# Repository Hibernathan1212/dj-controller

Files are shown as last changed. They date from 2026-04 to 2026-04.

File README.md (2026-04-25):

# DJ Controller

A MIDI jogless DJ controller similar to the Native Instruments S8 and D2 and X1 and Z1. Planning for it to just be a midi controller with knobs for mixing and controlling loops as well as buttons for play/pausing and others usually found on dj decks. Follows a modular design with the deck modules (2 on other side) and the mixer module which will have controls for 4 audio channels.

## Features

- Fully modular system
- 4 Audio track/channel support

## CAD

Consists of a base and a top lid that slots in a lip on the base. PCB is mounted to the lid with m2 screws that go into the faders and with the mx switches.

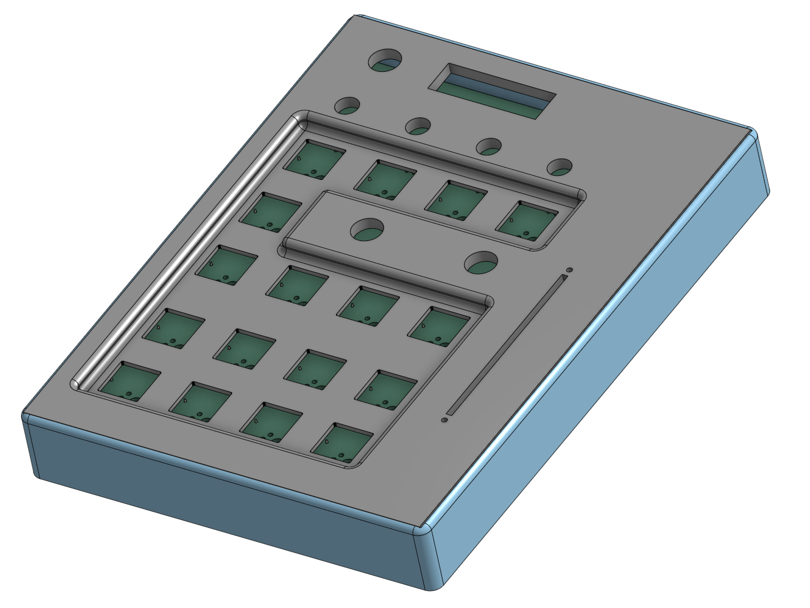
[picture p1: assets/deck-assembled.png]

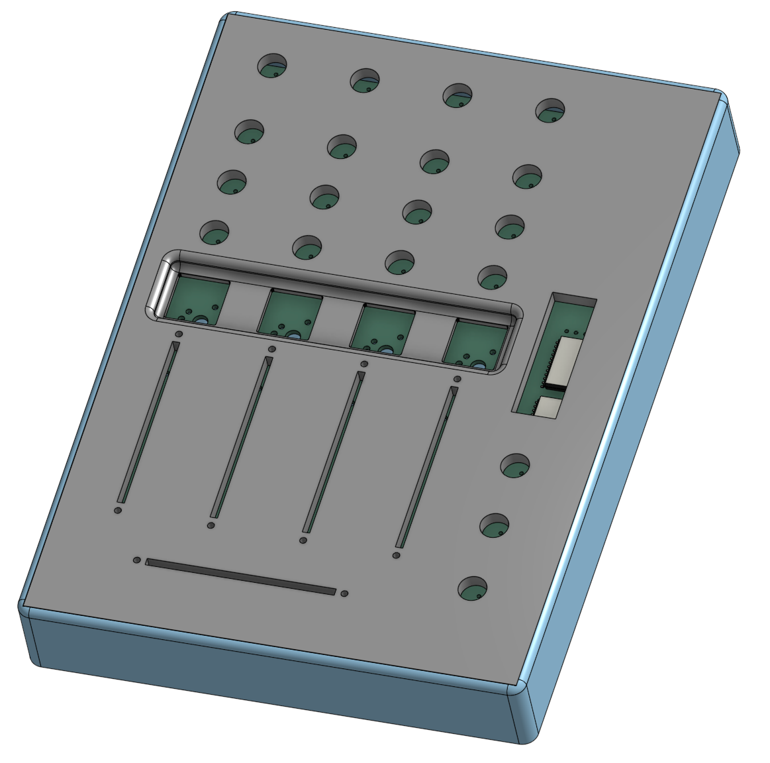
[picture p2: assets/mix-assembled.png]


Onshape links:
[mixer](https://cad.onshape.com/documents/8781b8df6f967f1c6b6a95c1/w/5dca202985c09c767b10b646/e/c48e65838657ec88be66024d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)
[deck](https://cad.onshape.com/documents/3b76899a1a1bc1a557b73df0/w/7b184ec473bdbf4286da5afb/e/11b981bd57d3e8bda80cba54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)

## PCB

Made in Kicad

### Schematic

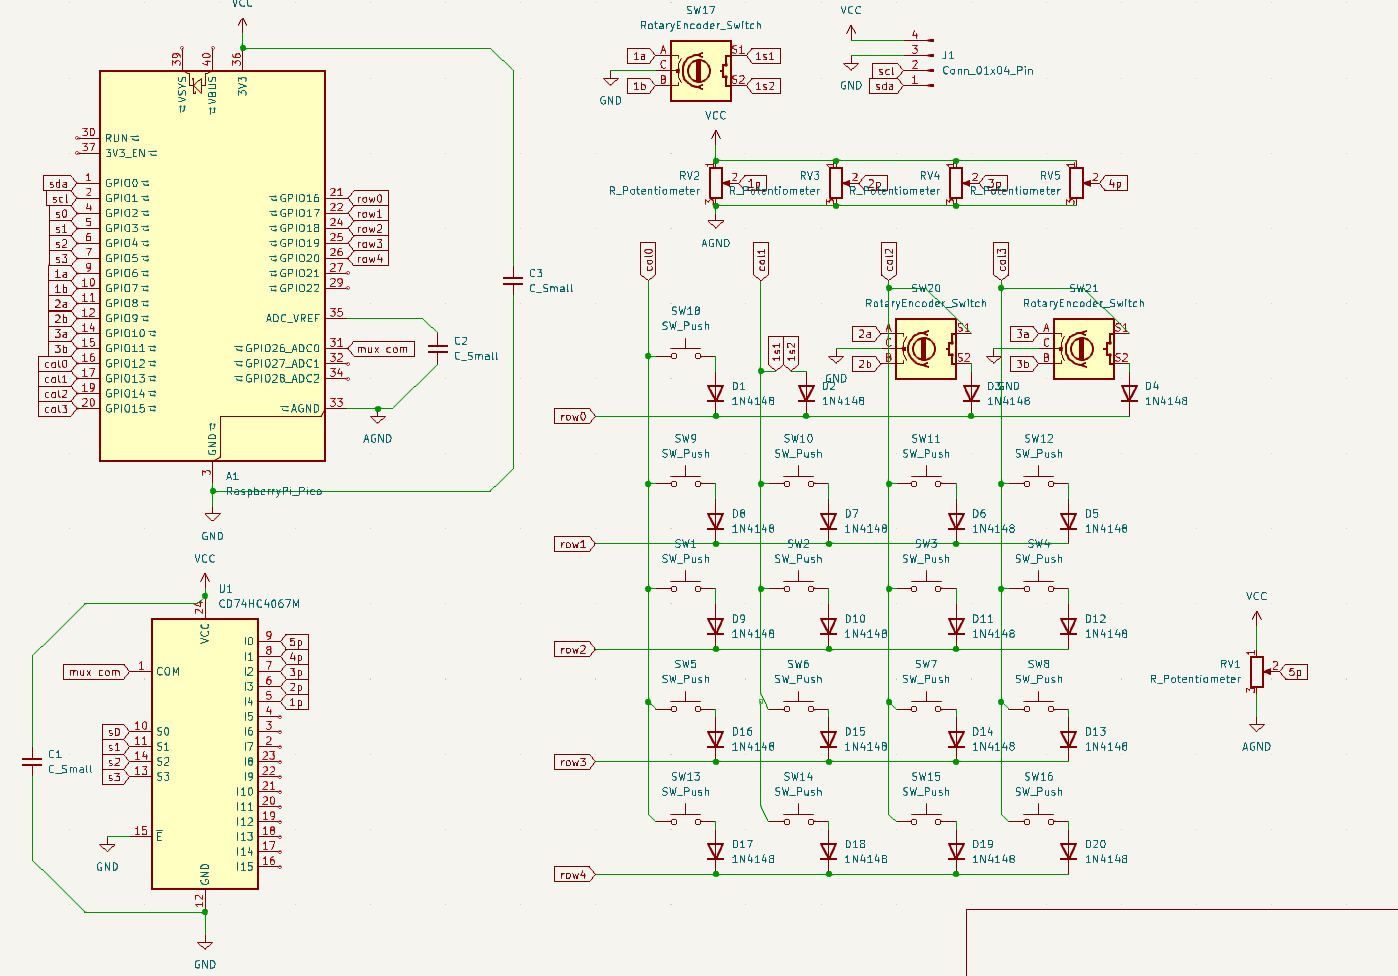
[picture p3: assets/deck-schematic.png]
schematic

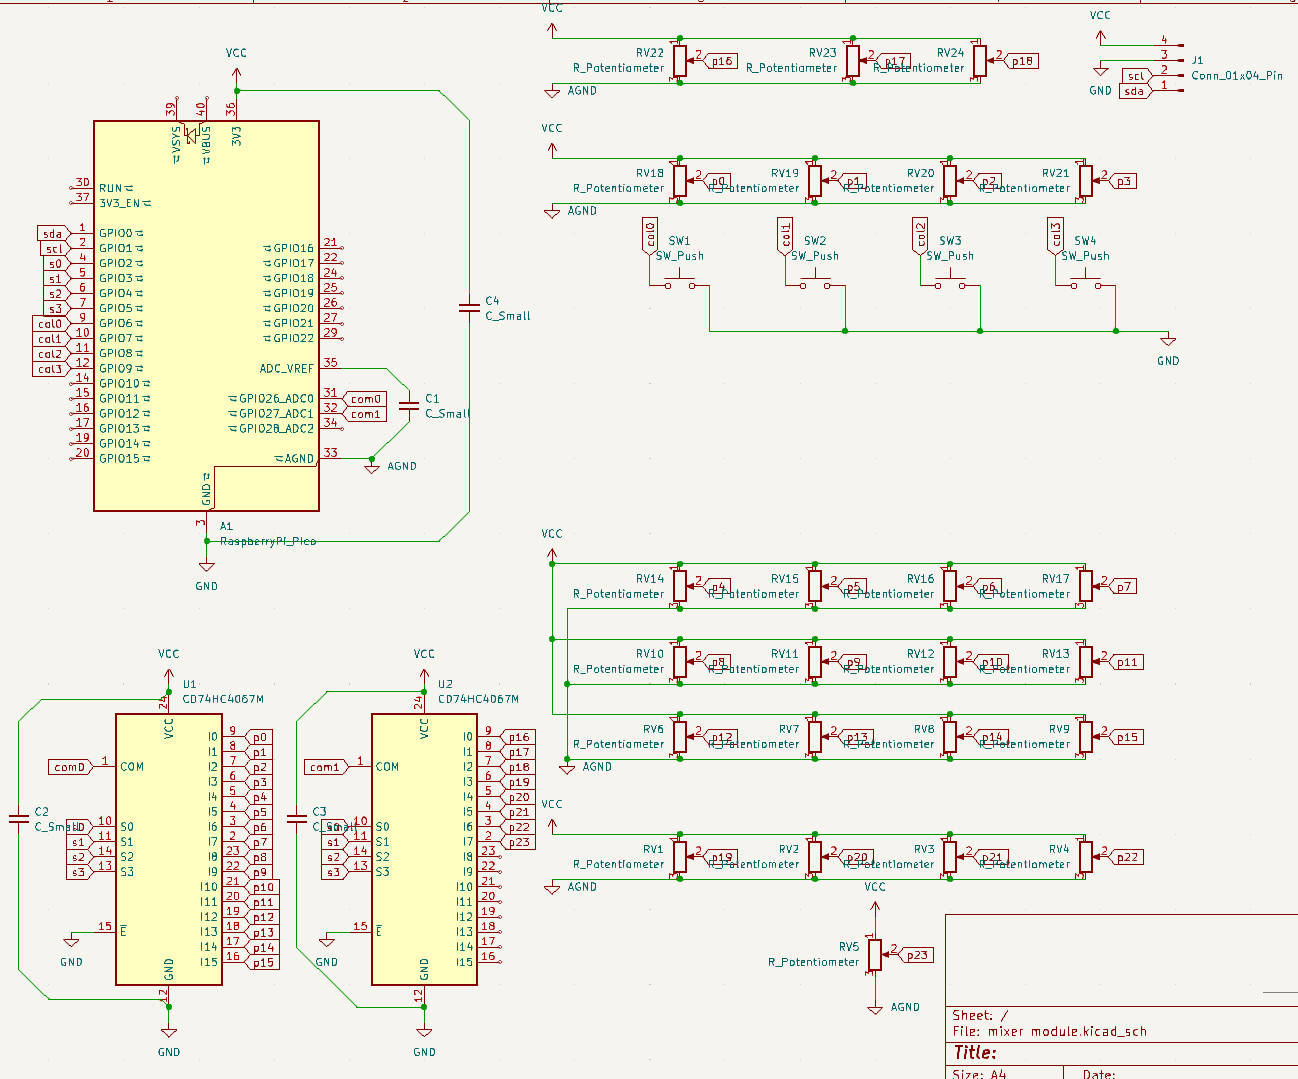
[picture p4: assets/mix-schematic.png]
schematic


### PCB

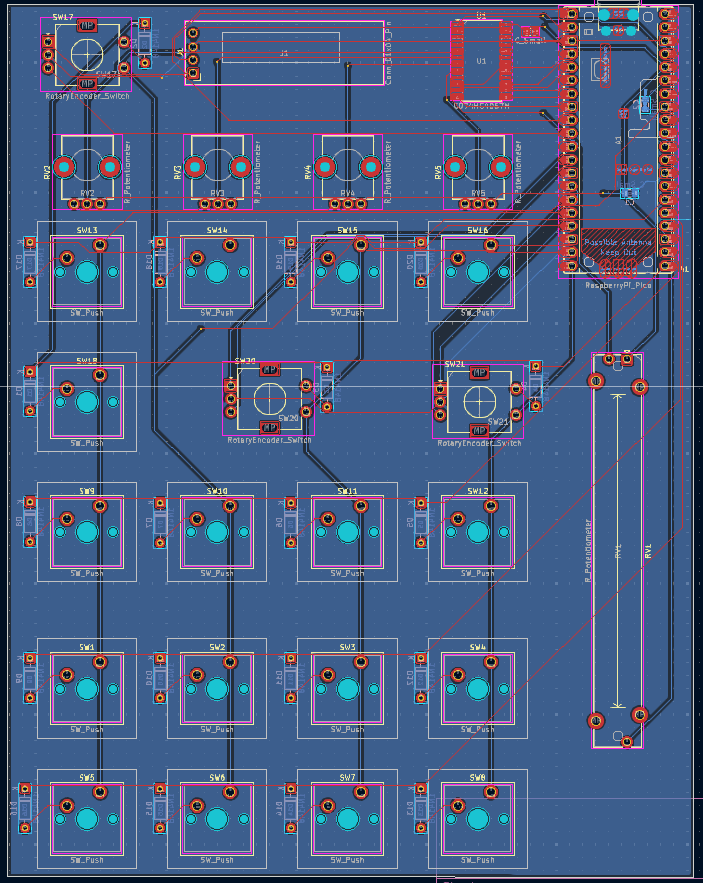
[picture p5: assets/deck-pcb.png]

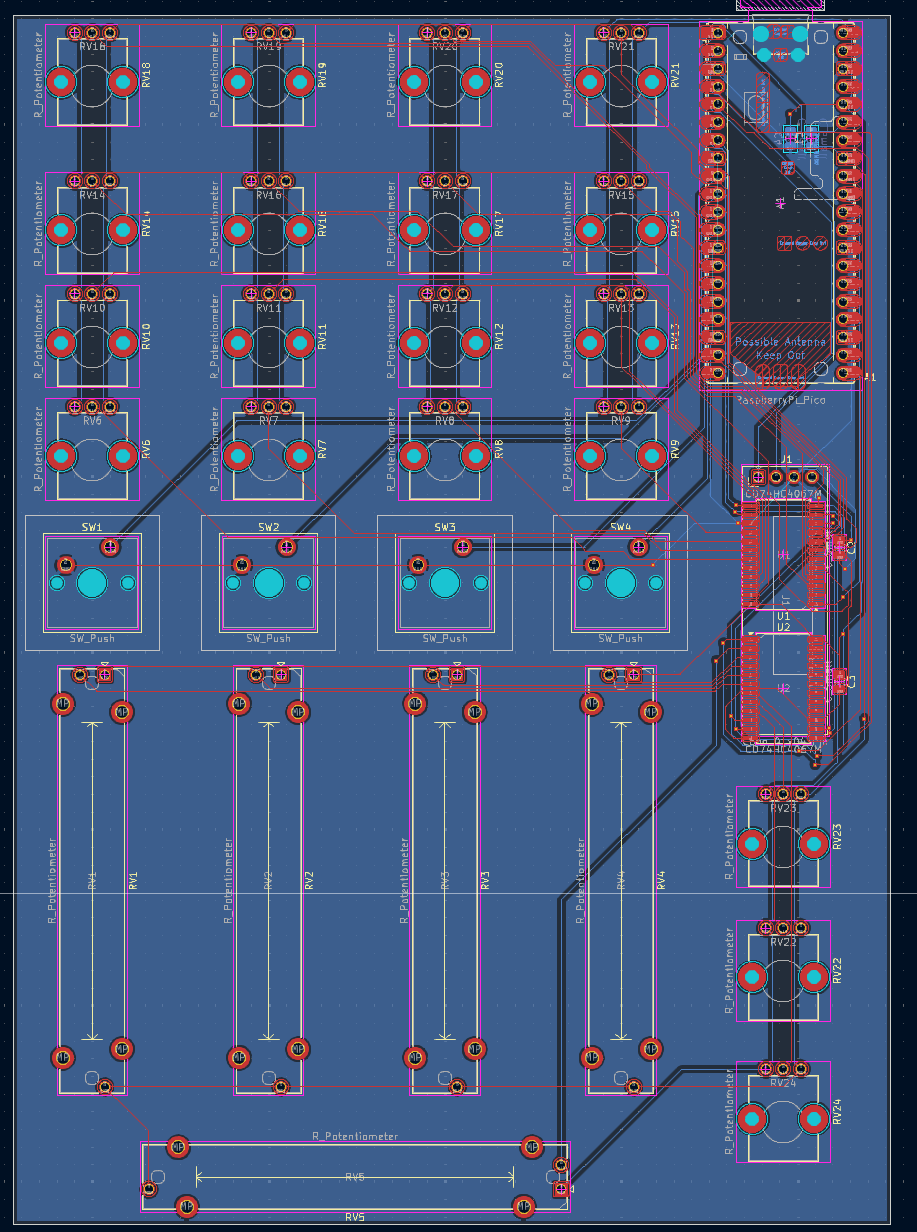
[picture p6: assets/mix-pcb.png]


## Firmware

Uses python with the usb midi library and adafruit to take the GPIO input and send midi signals back to the computer.

# BOM

| Product | Amount | Unit Cost (THB) | Price (THB) | Price (USD) | Link |
| --- | --- | --- | --- | --- | --- |
| CD74HC4067M | 4 | | 57.82 | 1.788156353 | [https://th.aliexpress.com/item/1005006425003395.html](https://th.aliexpress.com/item/1005006425003395.html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) |
| bourn pta6043 | 2 | 62.9 | 125.8 | 3.890523508 | [https://th.element14.com/bourns/pta6043-2015dpb103/potentiometer-slide-10k-20-0-25w/dp/1688411](https://th.element14.com/bourns/pta6043-2015dpb103/potentiometer-slide-10k-20-0-25w/dp/1688411) |
| bourn pta4543 | 5 | 53.73 | 268.65 | 8.308339749 | [https://th.element14.com/bourns/pta4543-2015dpb103/potentiometer-slide-10k-45mm/dp/1688415](https://th.element14.com/bourns/pta4543-2015dpb103/potentiometer-slide-10k-45mm/dp/1688415) |
| bourns ptv09a | 27 | 23.36 | 630.72 | 19.50581071 | [https://th.element14.com/bourns/ptv09a-4020f-b103/pot-rotary-10kohm-9mm-20/dp/2469524](https://th.element14.com/bourns/ptv09a-4020f-b103/pot-rotary-10kohm-9mm-20/dp/2469524) |
| 100nf 0805 smd capacitors | 10 | 0.43 | 4.3 | 0.132982918 | [https://th.element14.com/multicomp-pro/mc0805b104k250ct/cap-0-1-f-25v-10-x7r-0805/dp/1759166](https://th.element14.com/multicomp-pro/mc0805b104k250ct/cap-0-1-f-25v-10-x7r-0805/dp/1759166) |
| 6 alps ec11 | 6 | 81.42 | 488.52 | 15.10809654 | [https://th.element14.com/alps/ec11k1524402/encoder-vertical-11mm-30det-15ppr/dp/2064998](https://th.element14.com/alps/ec11k1524402/encoder-vertical-11mm-30det-15ppr/dp/2064998) |
| m2 screws | | | 154.17 | 4.767901504 | [https://th.element14.com/multicomp-pro/mp007338/screw-pan-head-pozidriv-m2-12mm/dp/3755264](https://th.element14.com/multicomp-pro/mp007338/screw-pan-head-pozidriv-m2-12mm/dp/3755264) |
| orpheus pico | 3 | ? | ? | 0 | |
| cherry switches | 40 | 60 | 240 | 7.4223024 | [https://www.lazada.co.th/products/pdp-i5447727976-s23110798561.html](https://www.lazada.co.th/products/pdp-i5447727976-s23110798561.html) |
| cherry keycaps | 38 | 280 | 560 | 17.3187056  | [https://www.lazada.co.th/products/lao8-20-key-xda-profile-pbt-keycaps-mechanical-keyboard-1u-1-x-ball-print-blank-customized-keycaps-mx-switches-xda-heighth-i1612850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](https://www.lazada.co.th/products/lao8-20-key-xda-profile-pbt-keycaps-mechanical-keyboard-1u-1-x-ball-print-blank-customized-keycaps-mx-switches-xda-heighth-i1612850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) |
| 3d print filament | 0.5 | 680 | 340 | 10.5149284  | [https://www.lazada.co.th/products/creality-hyper-petg-3d-printing-filament-1kg-175mm-plastic-filament-for-3d-printers-i5896245685-s126802674906.html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](https://www.lazada.co.th/products/creality-hyper-petg-3d-printing-filament-1kg-175mm-plastic-filament-for-3d-printers-i5896245685-s126802674906.html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) |
| jlcpcb | | | | 33.94 | |
| element 14 deliv | | | 550 | 17.009443 | |
| | | | | | |
| total | | | | 139.7071907 |

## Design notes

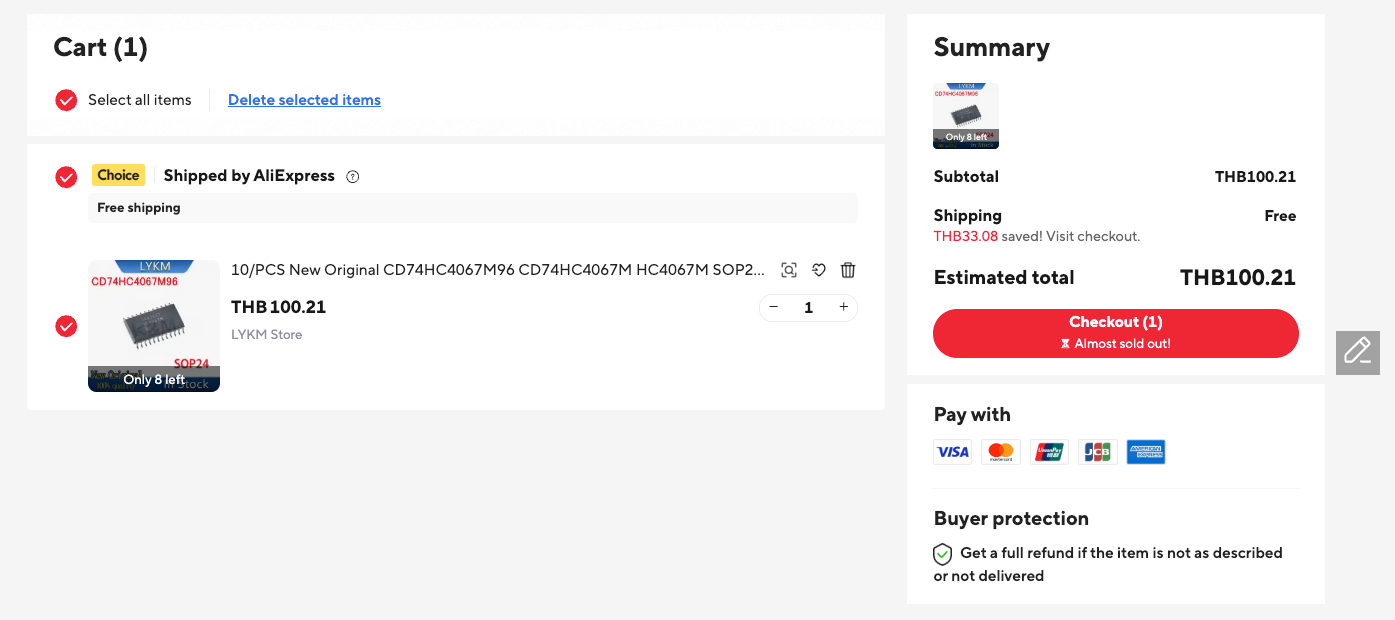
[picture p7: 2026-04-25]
assets/SCR-20260425-nbtz.png

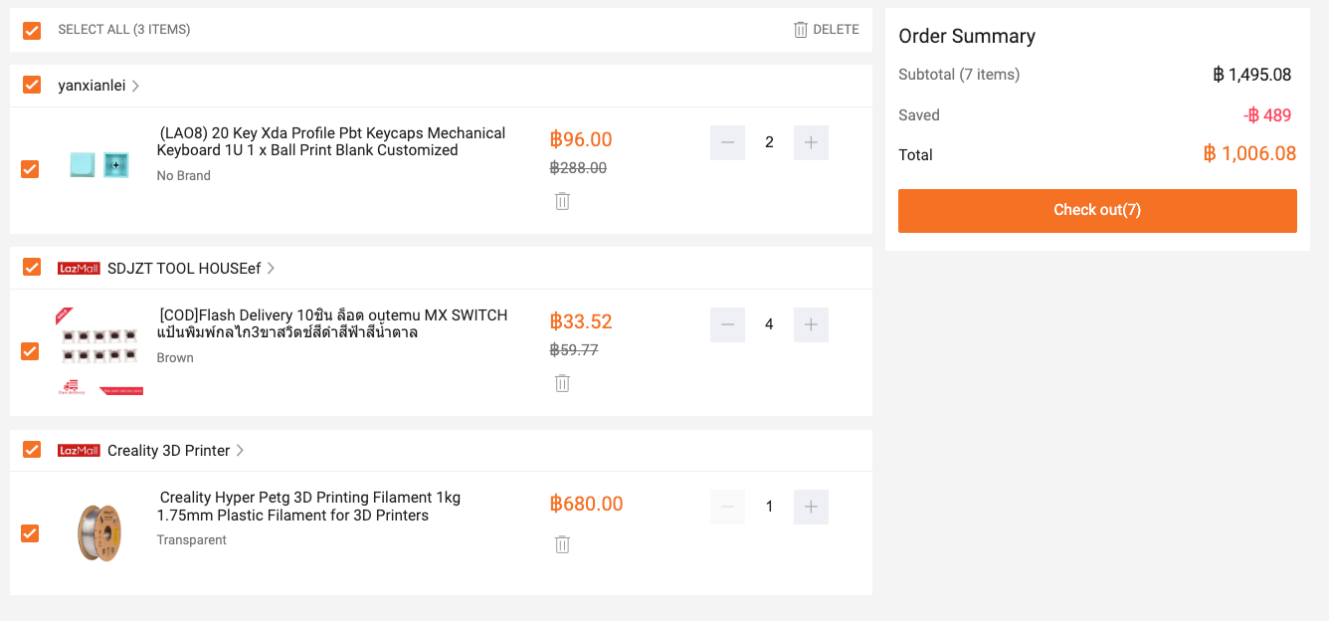
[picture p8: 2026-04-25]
assets/SCR-20260425-ngiw.png

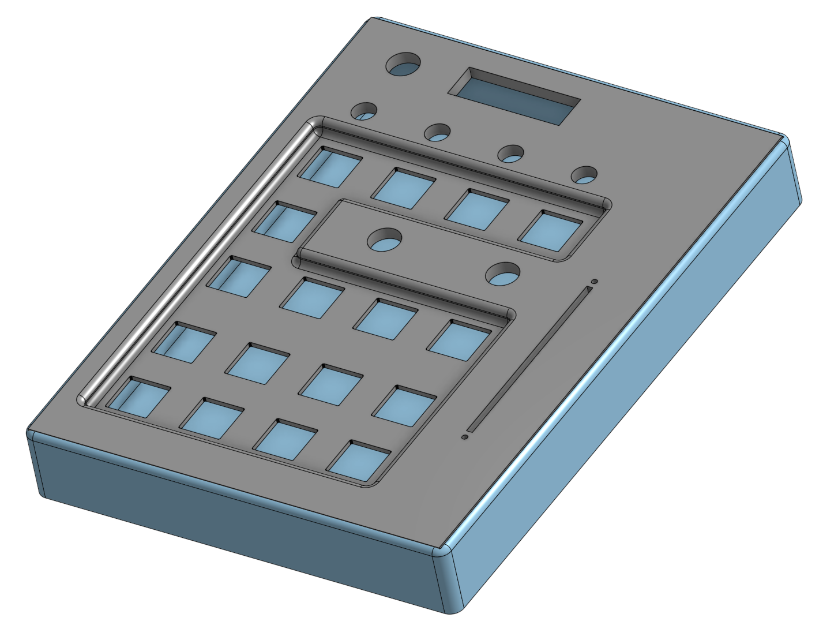
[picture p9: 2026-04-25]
assets/deck-cad.png

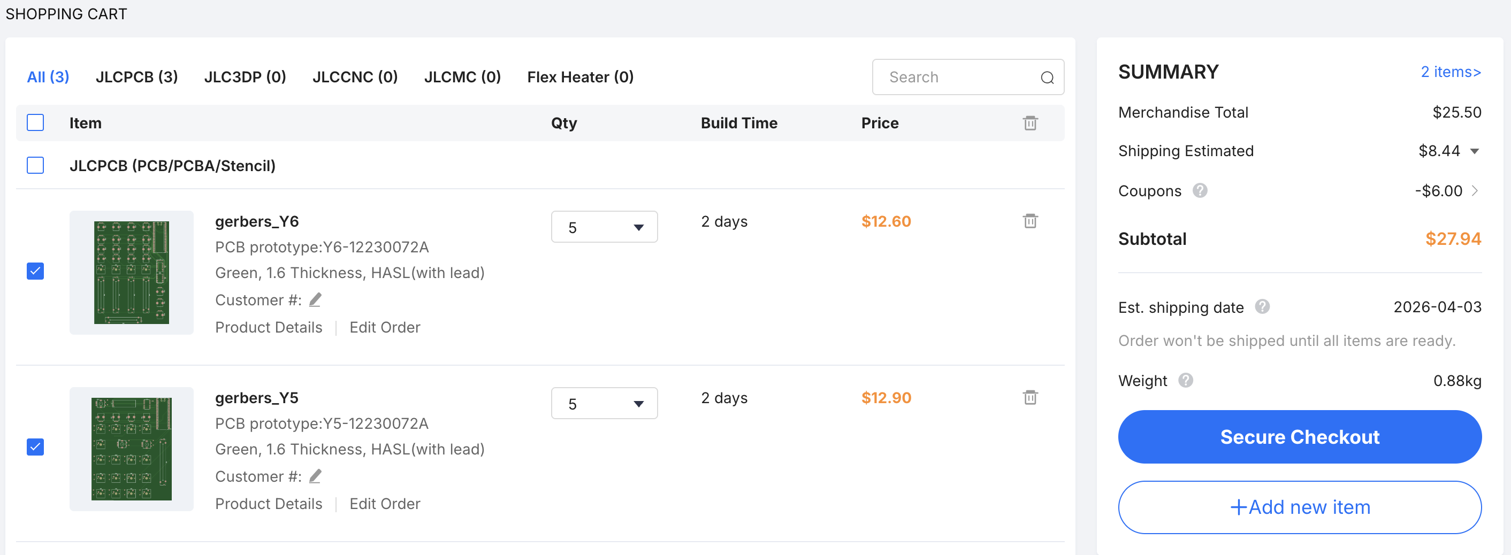
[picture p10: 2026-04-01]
assets/Screenshot 2026-04-01 at 10.44.30 AM.png

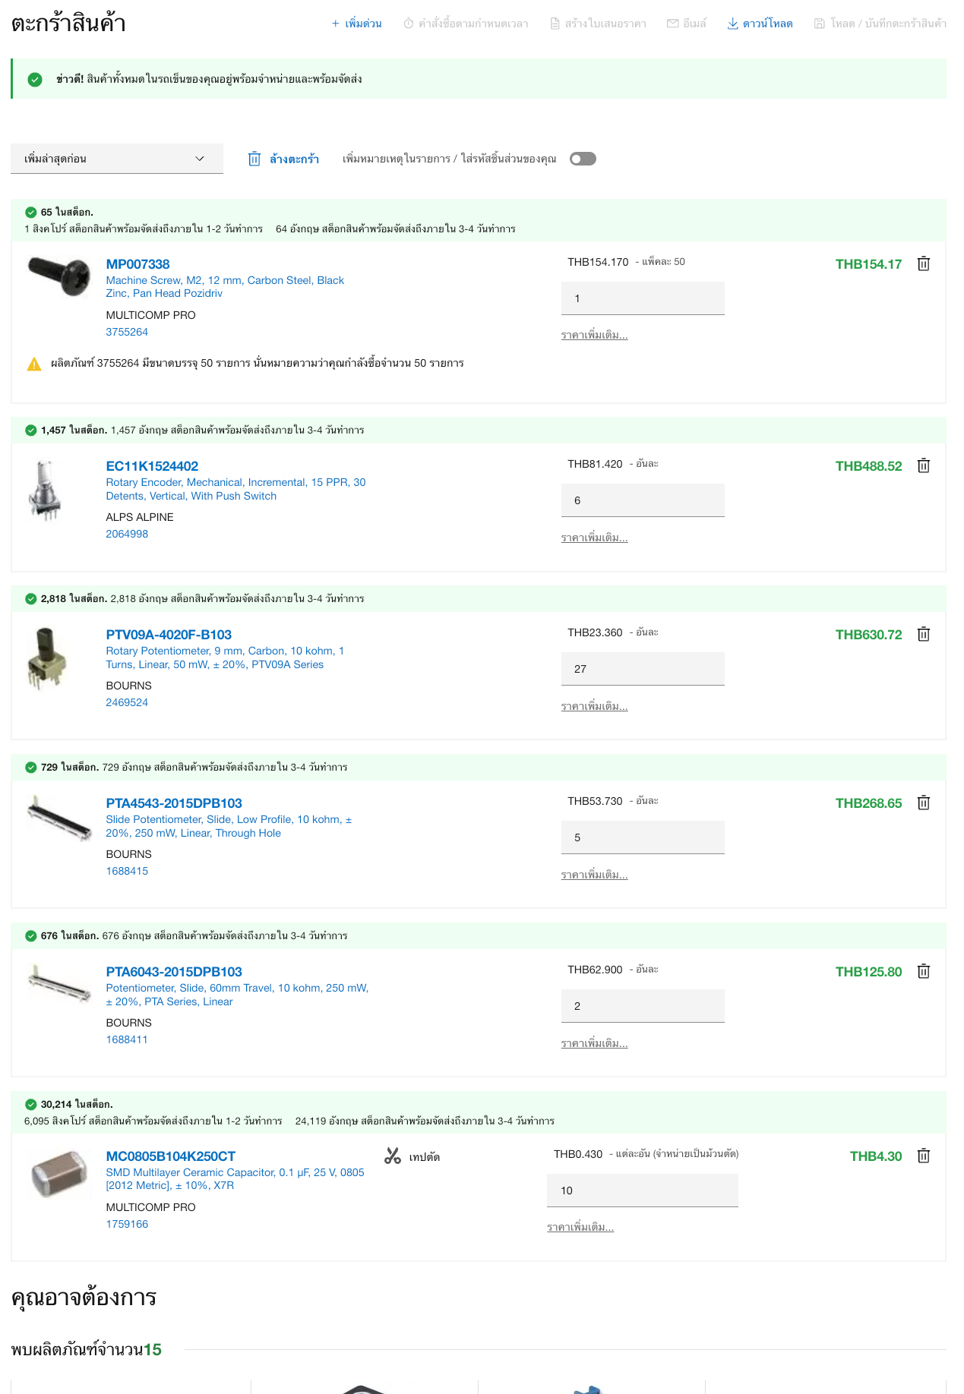
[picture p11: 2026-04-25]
assets/SCR-20260425-ndll.png

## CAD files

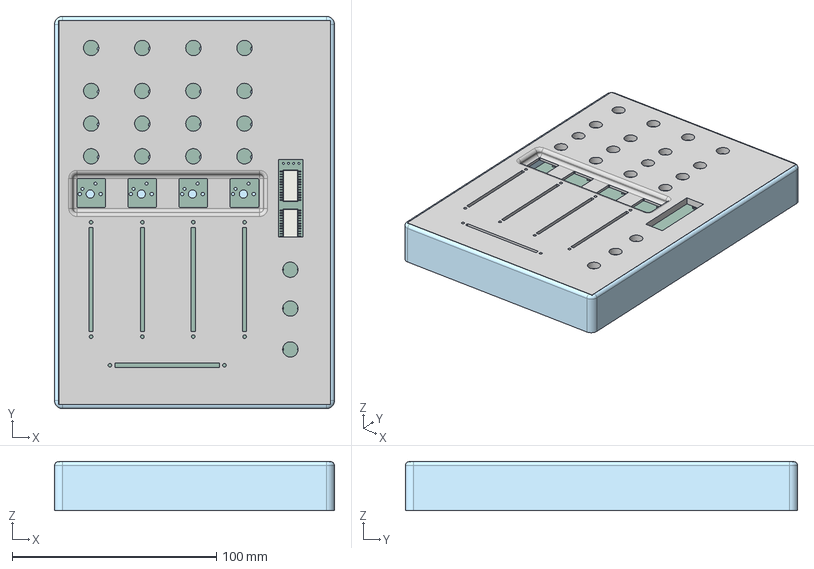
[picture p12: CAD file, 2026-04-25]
3d model/mixer assembled.step
137.0 x 192.0 x 24.1 mm
RaspberryPi_Pico_Module_KiCad
C_0805_2012Metric x 4
SOIC-24W_7.5x15.4mm_P1.27mm x 2
mixer module_PCB

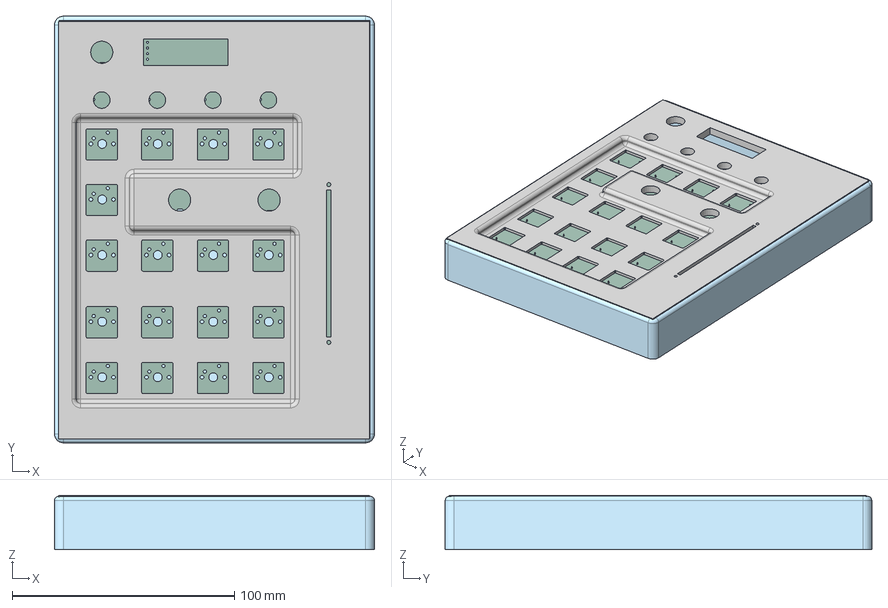
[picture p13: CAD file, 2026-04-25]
3d model/deck assembled.step
144.0 x 192.0 x 24.3 mm
D_DO-35_SOD27_P7.62mm_Horizontal x 40
C_0805_2012Metric x 3
SOIC-24W_7.5x15.4mm_P1.27mm
deck module_PCB
RaspberryPi_Pico_Module_KiCad

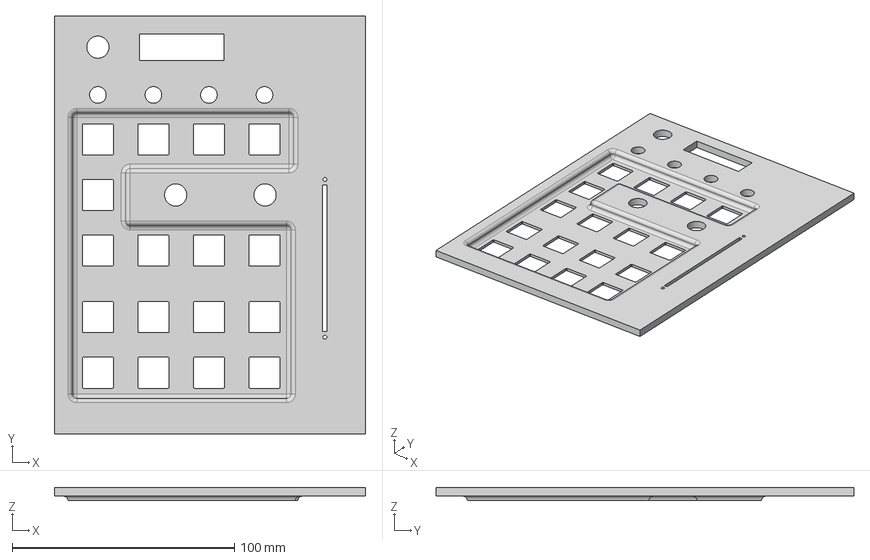
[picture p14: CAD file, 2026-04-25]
cad/deck top.step
140.0 x 188.0 x 6.00 mm

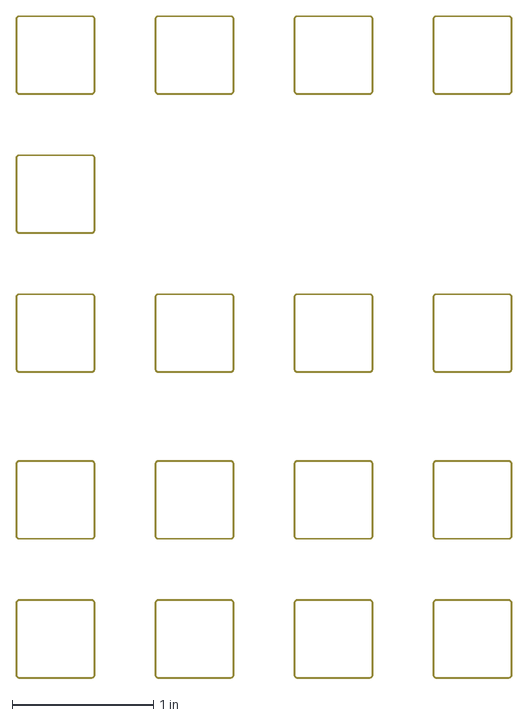
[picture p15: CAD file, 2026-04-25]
pcb/deck module/deck module.dxf
3.51 x 4.69 in

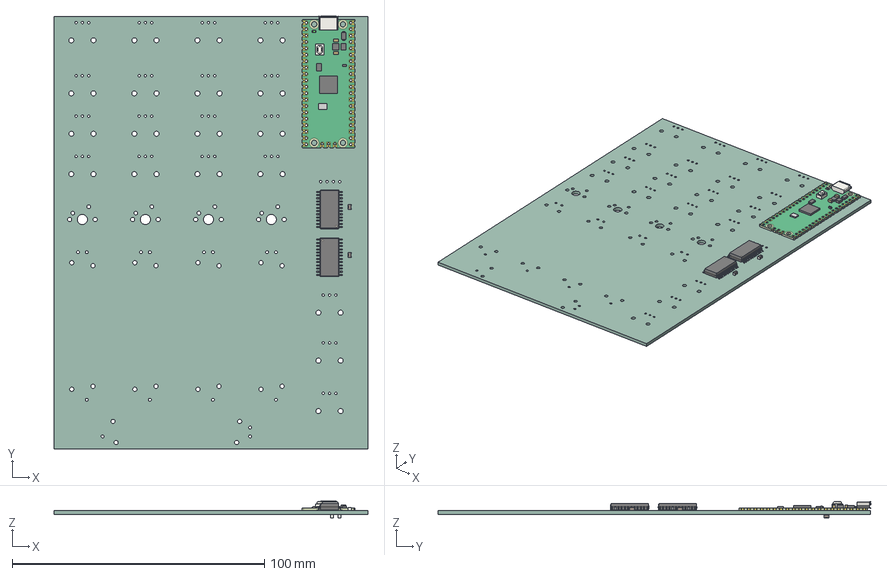
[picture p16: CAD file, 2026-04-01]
pcb/mix module/pcb.step
124.5 x 171.7 x 6.63 mm
C_0805_2012Metric x 4
SOIC-24W_7.5x15.4mm_P1.27mm x 2
RaspberryPi_Pico_Module_KiCad
mixer module_PCB

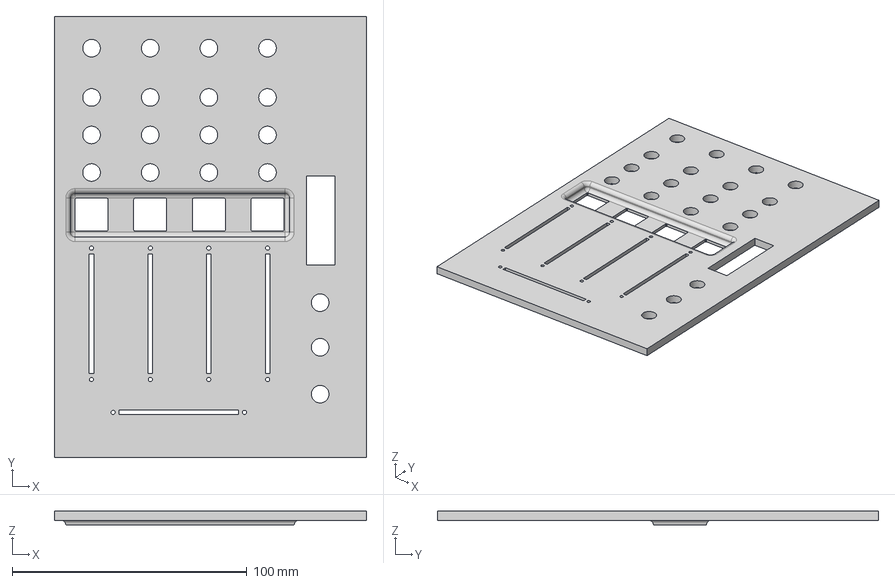
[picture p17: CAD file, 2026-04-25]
cad/mixer top.step
133.0 x 188.0 x 6.00 mm

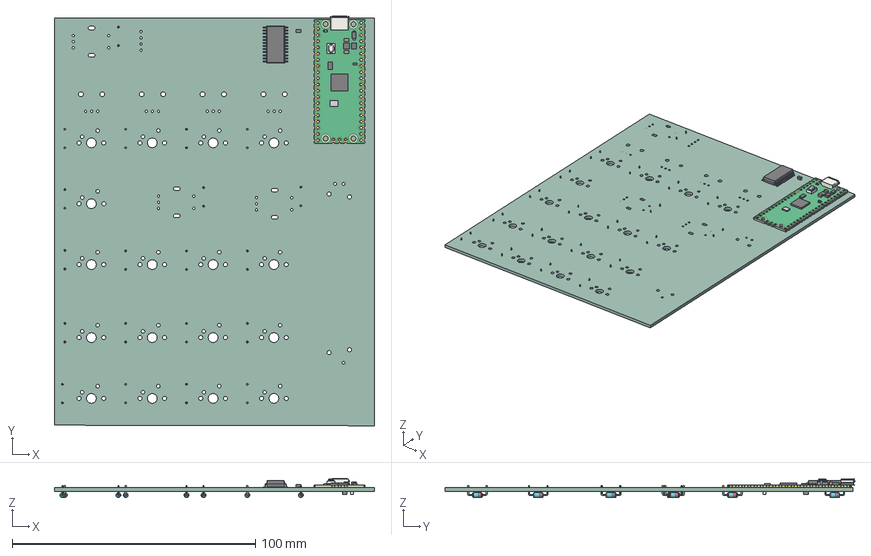
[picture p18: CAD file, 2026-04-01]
pcb/deck module/pcb.step
131.5 x 168.3 x 7.89 mm
SOIC-24W_7.5x15.4mm_P1.27mm
C_0805_2012Metric x 3
RaspberryPi_Pico_Module_KiCad
D_DO-35_SOD27_P7.62mm_Horizontal x 20
deck module_PCB

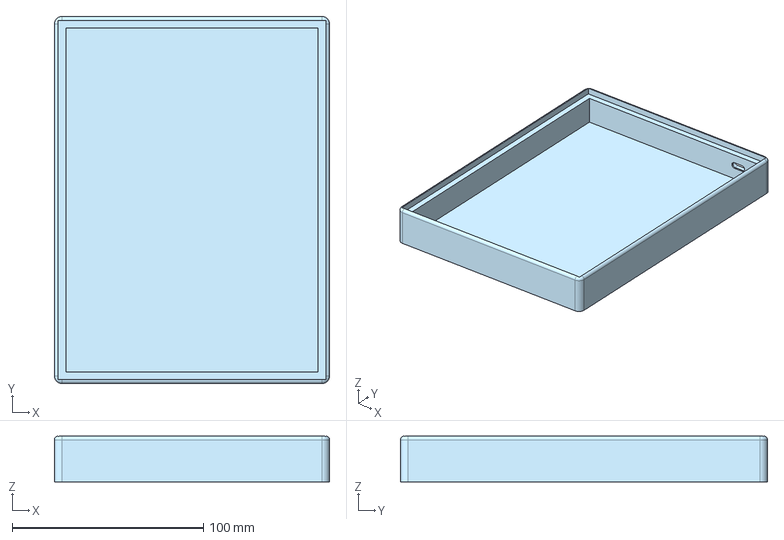
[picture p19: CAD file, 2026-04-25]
cad/deck bottom.step
144.0 x 192.0 x 24.0 mm

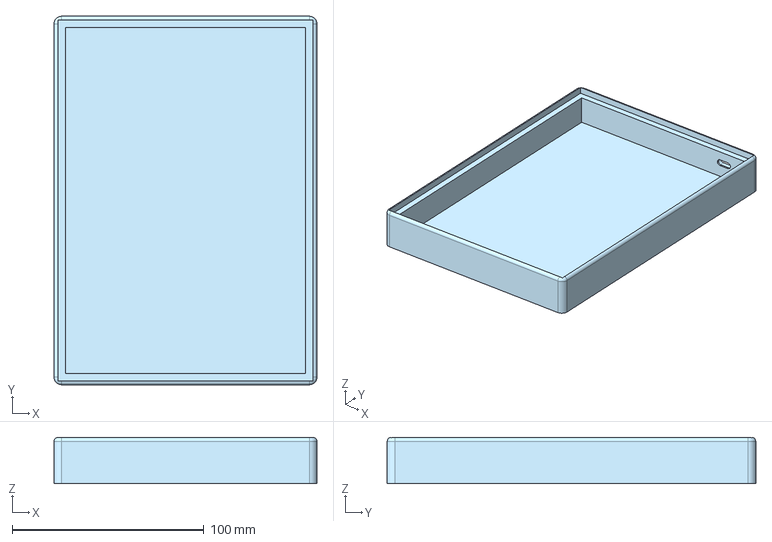
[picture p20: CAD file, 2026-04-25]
cad/mixer bottom.step
137.0 x 192.0 x 24.0 mm

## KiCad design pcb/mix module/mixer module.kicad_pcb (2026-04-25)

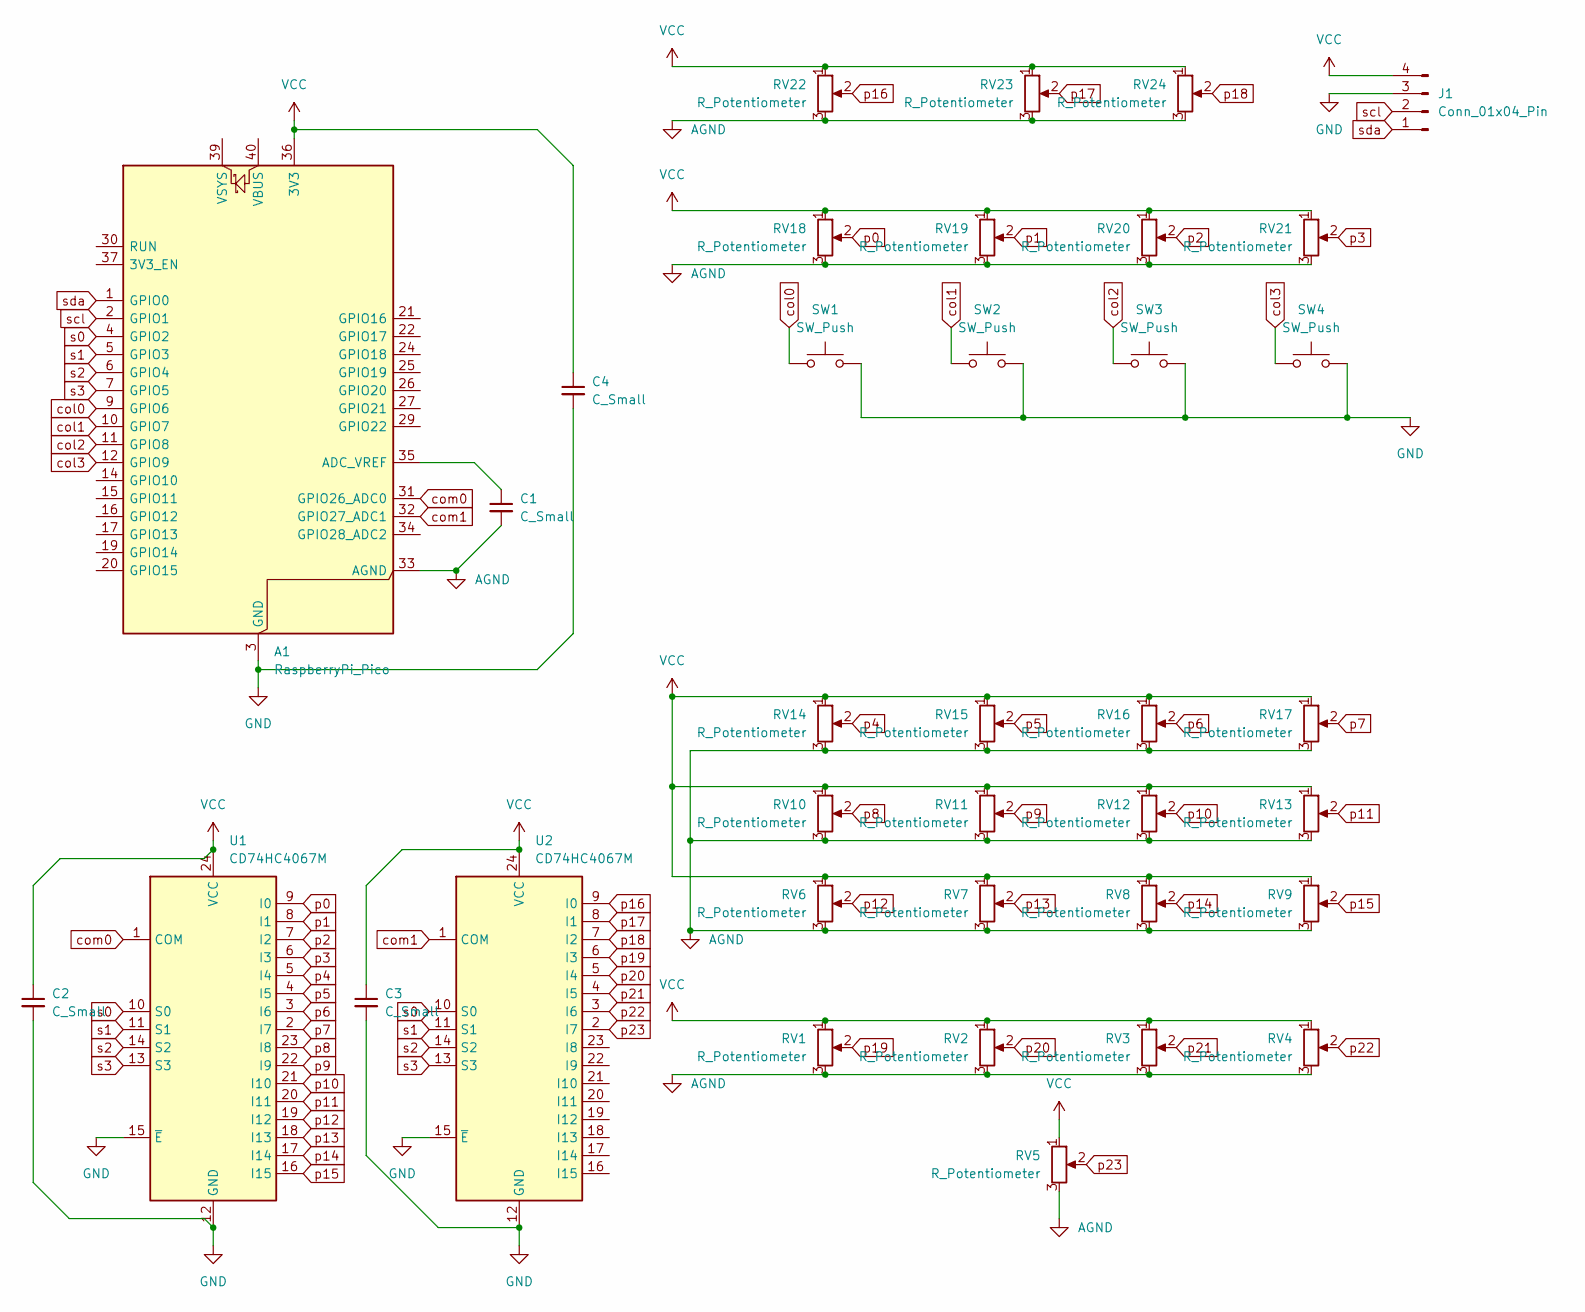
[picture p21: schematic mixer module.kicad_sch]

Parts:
A1: RaspberryPi_Pico; RaspberryPi_Pico_Common_Unspecified
C1, C2, C3, C4: C_Small; C_0805_2012Metric_Pad1.18x1.45mm_HandSolder
J1: Conn_01x04_Pin; ER_OLEDM0.91_1x-I2C
RV1, RV2, RV3, RV4, RV5: R_Potentiometer; Potentiometer_Bourns_PTA4543_Single_Slide
RV6, RV7, RV8, RV9, RV10, RV11, RV12, RV13, RV14, RV15, RV16, RV17, RV18, RV19, RV20, RV21, RV22, RV23, RV24: R_Potentiometer; Potentiometer_Bourns_PTV09A-1_Single_Vertical
SW1, SW2, SW3, SW4: SW_Push; SW_Cherry_MX_1.00u_PCB
U1, U2: CD74HC4067M; SOIC-24W_7.5x15.4mm_P1.27mm

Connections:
AGND: A1.33 (AGND), C1.2, RV1.3, RV2.3, RV3.3, RV4.3, RV5.3, RV6.3, RV7.3, RV8.3, RV9.3, RV10.3, RV11.3, RV12.3, RV13.3, RV14.3, RV15.3, RV16.3, RV17.3, RV18.3, RV19.3, RV20.3, RV21.3, RV22.3, RV23.3, RV24.3
GND: A1.3 (GND), A1.8 (GND), A1.13 (GND), A1.18 (GND), A1.23 (GND), A1.28 (GND), A1.38 (GND), C2.2, C3.2, C4.2, J1.3, SW1.2, SW2.2, SW3.2, SW4.2, U1.12 (GND), U1.15 (~E), U2.12 (GND), U2.15 (~E)
unnamed: A1.35 (ADC_VREF), C1.1
VCC: A1.36 (3V3), C2.1, C3.1, C4.1, J1.4, RV1.1, RV2.1, RV3.1, RV4.1, RV5.1, RV6.1, RV7.1, RV8.1, RV9.1, RV10.1, RV11.1, RV12.1, RV13.1, RV14.1, RV15.1, RV16.1, RV17.1, RV18.1, RV19.1, RV20.1, RV21.1, RV22.1, RV23.1, RV24.1, U1.24 (VCC), U2.24 (VCC)
col0: A1.9 (GPIO6), SW1.1
col1: A1.10 (GPIO7), SW2.1
col2: A1.11 (GPIO8), SW3.1
col3: A1.12 (GPIO9), SW4.1
com0: A1.31 (GPIO26_ADC0), U1.1 (COM)
com1: A1.32 (GPIO27_ADC1), U2.1 (COM)
p0: RV18.2, U1.9 (I0)
p1: RV19.2, U1.8 (I1)
p2: RV20.2, U1.7 (I2)
p3: RV21.2, U1.6 (I3)
p4: RV14.2, U1.5 (I4)
p5: RV15.2, U1.4 (I5)
p6: RV16.2, U1.3 (I6)
p7: RV17.2, U1.2 (I7)
p8: RV10.2, U1.23 (I8)
p9: RV11.2, U1.22 (I9)
p10: RV12.2, U1.21 (I10)
p11: RV13.2, U1.20 (I11)
p12: RV6.2, U1.19 (I12)
p13: RV7.2, U1.18 (I13)
p14: RV8.2, U1.17 (I14)
p15: RV9.2, U1.16 (I15)
p16: RV22.2, U2.9 (I0)
p17: RV23.2, U2.8 (I1)
p18: RV24.2, U2.7 (I2)
p19: RV1.2, U2.6 (I3)
p20: RV2.2, U2.5 (I4)
p21: RV3.2, U2.4 (I5)
p22: RV4.2, U2.3 (I6)
p23: RV5.2, U2.2 (I7)
s0: A1.4 (GPIO2), U1.10 (S0), U2.10 (S0)
s1: A1.5 (GPIO3), U1.11 (S1), U2.11 (S1)
s2: A1.6 (GPIO4), U1.14 (S2), U2.14 (S2)
s3: A1.7 (GPIO5), U1.13 (S3), U2.13 (S3)
scl: A1.2 (GPIO1), J1.2
sda: A1.1 (GPIO0), J1.1

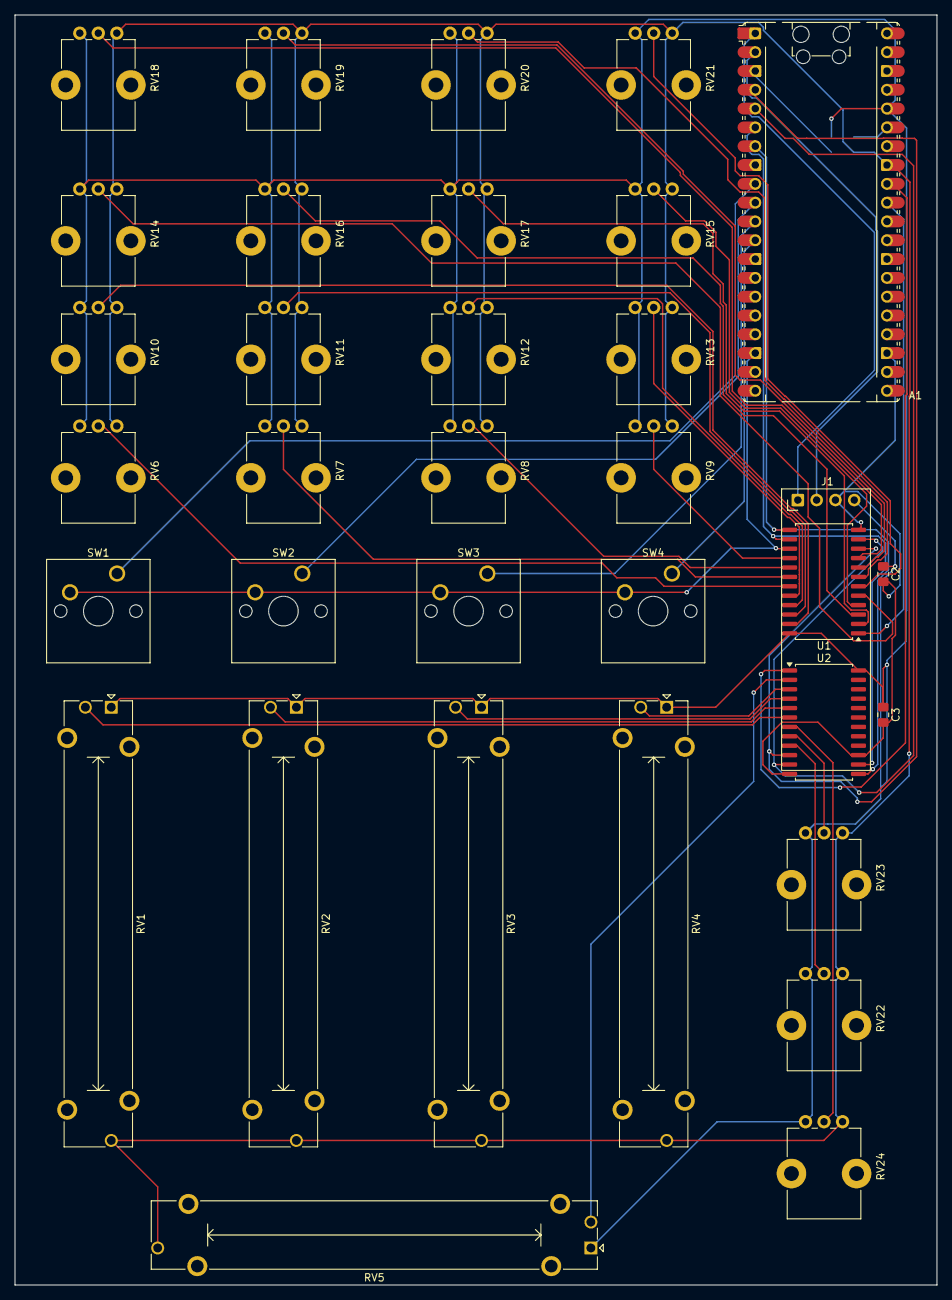
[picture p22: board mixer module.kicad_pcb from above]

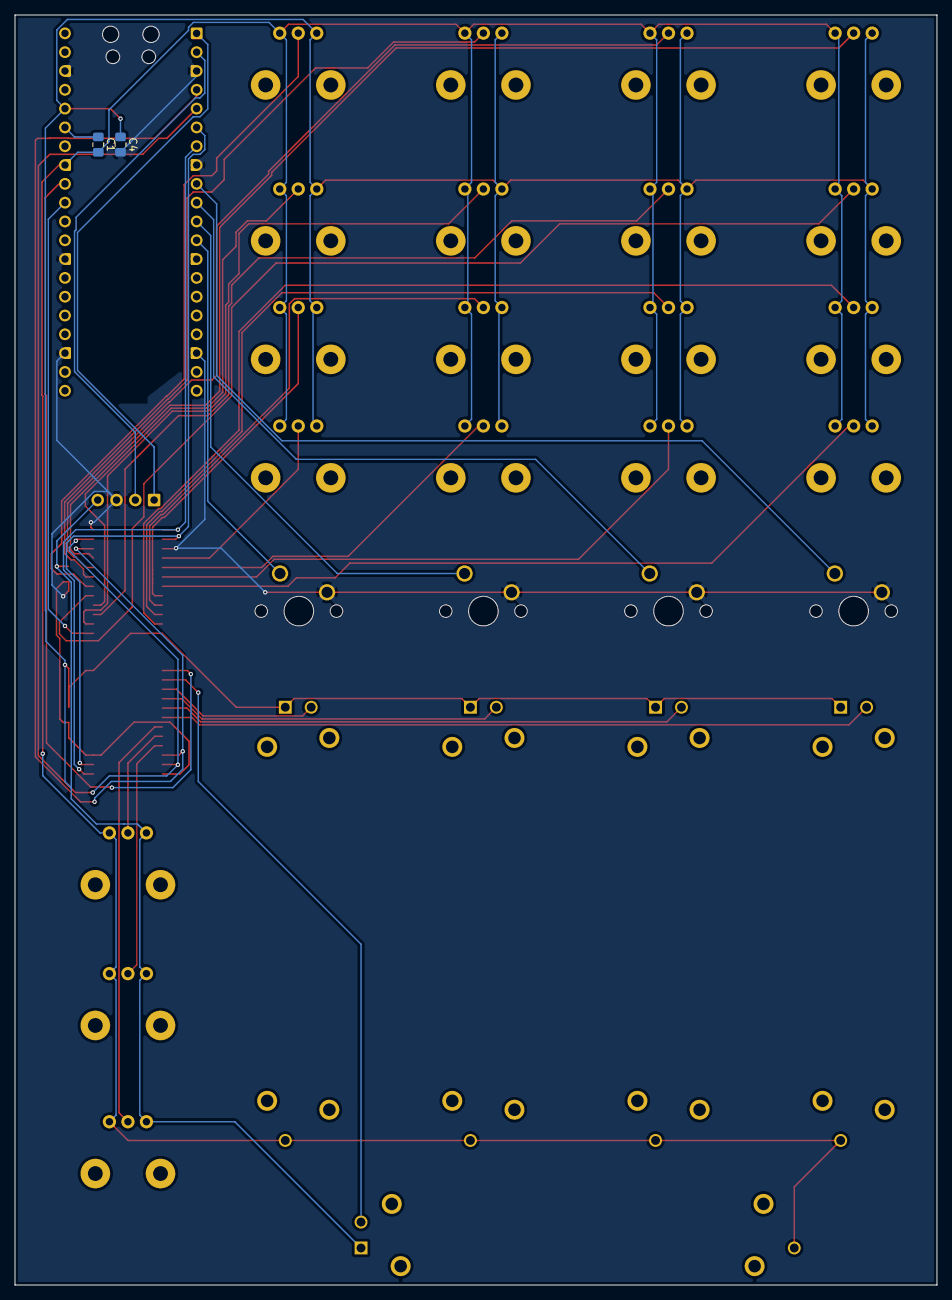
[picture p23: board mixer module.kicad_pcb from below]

Board: 2 copper layers, 124.5 x 171.5 mm, 36 parts (2 on the bottom side), 40 nets.

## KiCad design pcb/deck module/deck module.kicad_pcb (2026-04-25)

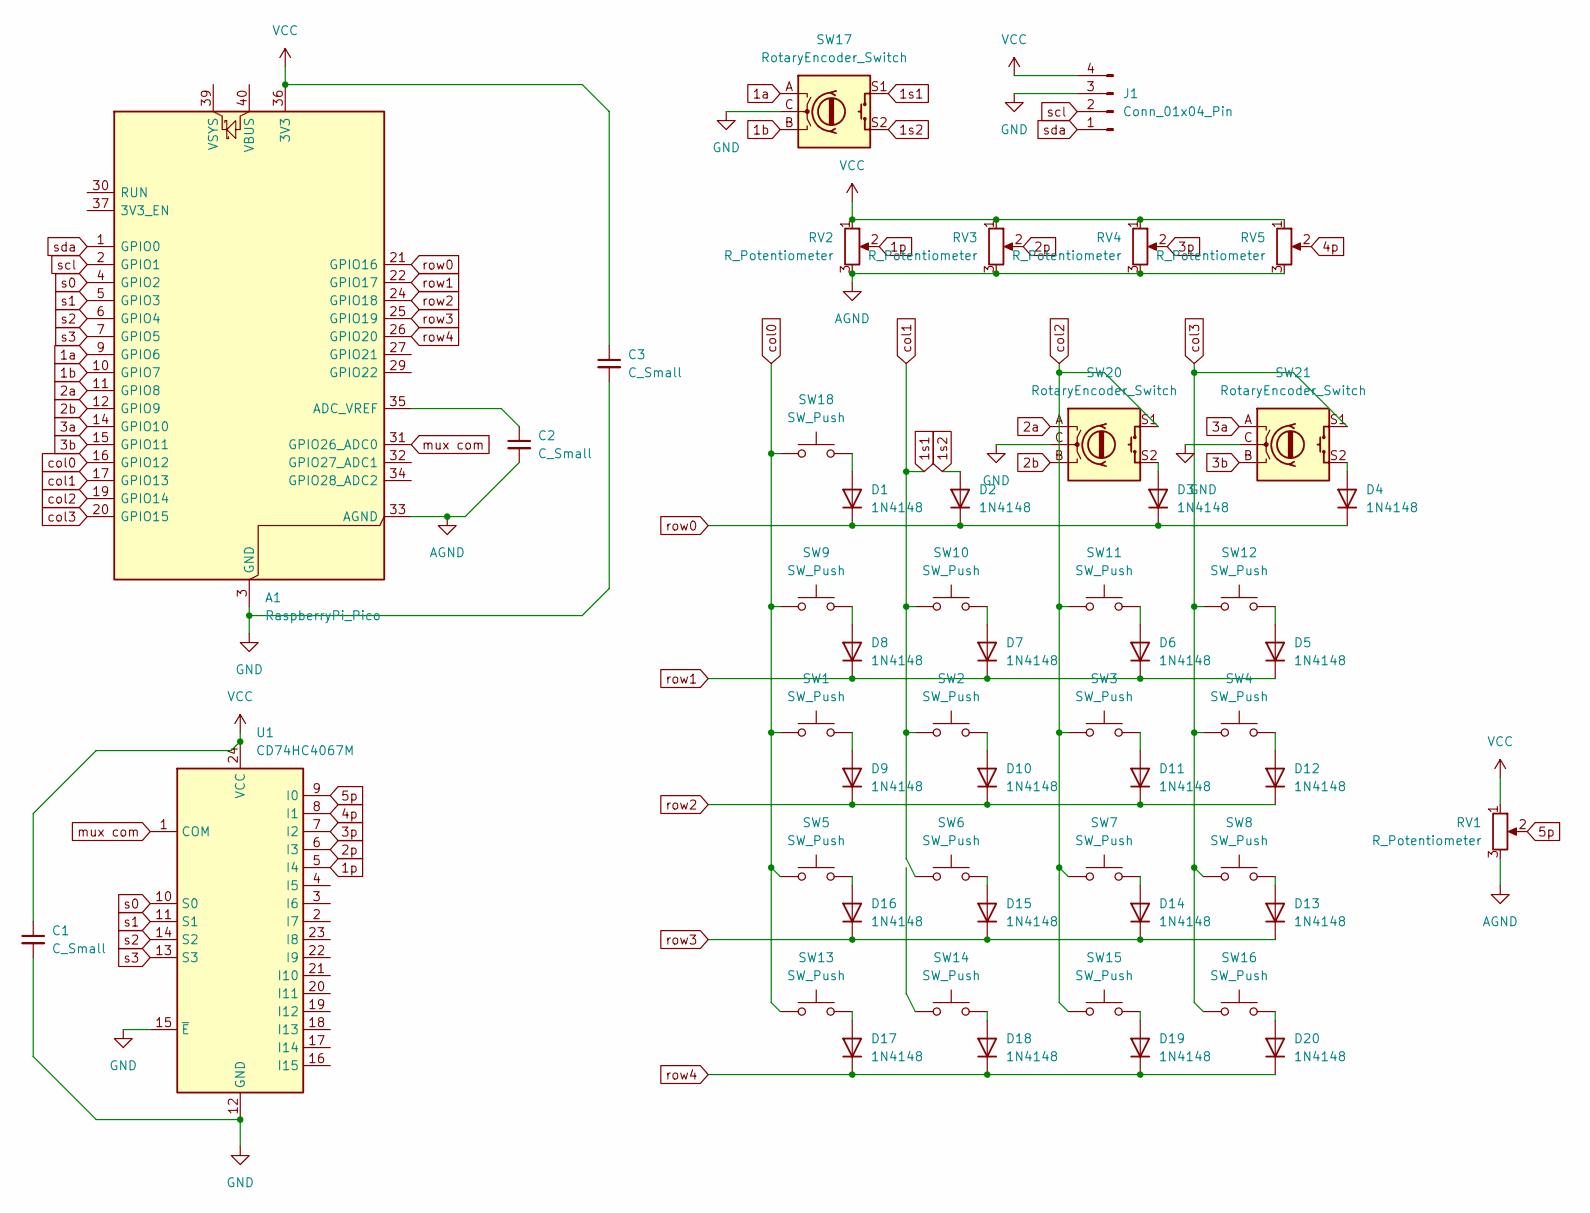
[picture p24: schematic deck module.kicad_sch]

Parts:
A1: RaspberryPi_Pico; RaspberryPi_Pico_Common_Unspecified
C1, C2, C3: C_Small; C_0805_2012Metric
D1, D2, D3, D4, D5, D6, D7, D8, D9, D10, D11, D12, D13, D14, D15, D16, D17, D18, D19, D20: 1N4148; D_DO-35_SOD27_P7.62mm_Horizontal
J1: Conn_01x04_Pin; ER_OLEDM0.91_1x-I2C
RV1: R_Potentiometer; Potentiometer_Bourns_PTA6043_Single_Slide
RV2, RV3, RV4, RV5: R_Potentiometer; Potentiometer_Bourns_PTV09A-1_Single_Vertical
SW1, SW2, SW3, SW4, SW5, SW6, SW7, SW8, SW9, SW10, SW11, SW12, SW13, SW14, SW15, SW16, SW18: SW_Push; SW_MX_1u
SW17, SW20, SW21: RotaryEncoder_Switch; RotaryEncoder_Alps_EC11E-Switch_Vertical_H20mm
U1: CD74HC4067M; SOIC-24W_7.5x15.4mm_P1.27mm

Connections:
1a: A1.9 (GPIO6), SW17.A
1b: A1.10 (GPIO7), SW17.B
1p: RV2.2, U1.5 (I4)
1s1: A1.17 (GPIO13), SW2.1, SW6.1, SW10.1, SW17.S1
1s2: D2.2 (A), SW17.S2
2a: A1.11 (GPIO8), SW20.A
2b: A1.12 (GPIO9), SW20.B
2p: RV3.2, U1.6 (I3)
3a: A1.14 (GPIO10), SW21.A
3b: A1.15 (GPIO11), SW21.B
3p: RV4.2, U1.7 (I2)
4p: RV5.2, U1.8 (I1)
5p: RV1.2, U1.9 (I0)
AGND: A1.33 (AGND), C2.2, RV1.3, RV2.3, RV3.3, RV4.3, RV5.3
GND: A1.3 (GND), A1.8 (GND), A1.13 (GND), A1.18 (GND), A1.23 (GND), A1.28 (GND), A1.38 (GND), C1.2, C3.2, J1.3, SW17.C, SW20.C, SW21.C, U1.12 (GND), U1.15 (~E)
unnamed: A1.35 (ADC_VREF), C2.1
unnamed: D1.2 (A), SW18.2
unnamed: D3.2 (A), SW20.S2
unnamed: D4.2 (A), SW21.S2
unnamed: D5.2 (A), SW12.2
unnamed: D6.2 (A), SW11.2
unnamed: D7.2 (A), SW10.2
unnamed: D8.2 (A), SW9.2
unnamed: D9.2 (A), SW1.2
unnamed: D10.2 (A), SW2.2
unnamed: D11.2 (A), SW3.2
unnamed: D12.2 (A), SW4.2
unnamed: D13.2 (A), SW8.2
unnamed: D14.2 (A), SW7.2
unnamed: D15.2 (A), SW6.2
unnamed: D16.2 (A), SW5.2
unnamed: D17.2 (A), SW13.2
unnamed: D18.2 (A), SW14.2 (2_2)
unnamed: D19.2 (A), SW15.2
unnamed: D20.2 (A), SW16.2
VCC: A1.36 (3V3), C1.1, C3.1, J1.4, RV1.1, RV2.1, RV3.1, RV4.1, RV5.1, U1.24 (VCC)
col0: A1.16 (GPIO12), SW1.1, SW5.1, SW9.1, SW13.1, SW18.1
col2: A1.19 (GPIO14), SW3.1, SW7.1, SW11.1, SW15.1, SW20.S1
col3: A1.20 (GPIO15), SW4.1, SW8.1, SW12.1, SW16.1, SW21.S1
mux com: A1.31 (GPIO26_ADC0), U1.1 (COM)
row0: A1.21 (GPIO16), D1.1 (K), D2.1 (K), D3.1 (K), D4.1 (K)
row1: A1.22 (GPIO17), D5.1 (K), D6.1 (K), D7.1 (K), D8.1 (K)
row2: A1.24 (GPIO18), D9.1 (K), D10.1 (K), D11.1 (K), D12.1 (K)
row3: A1.25 (GPIO19), D13.1 (K), D14.1 (K), D15.1 (K), D16.1 (K)
row4: A1.26 (GPIO20), D17.1 (K), D18.1 (K), D19.1 (K), D20.1 (K)
s0: A1.4 (GPIO2), U1.10 (S0)
s1: A1.5 (GPIO3), U1.11 (S1)
s2: A1.6 (GPIO4), U1.14 (S2)
s3: A1.7 (GPIO5), U1.13 (S3)
scl: A1.2 (GPIO1), J1.2
sda: A1.1 (GPIO0), J1.1

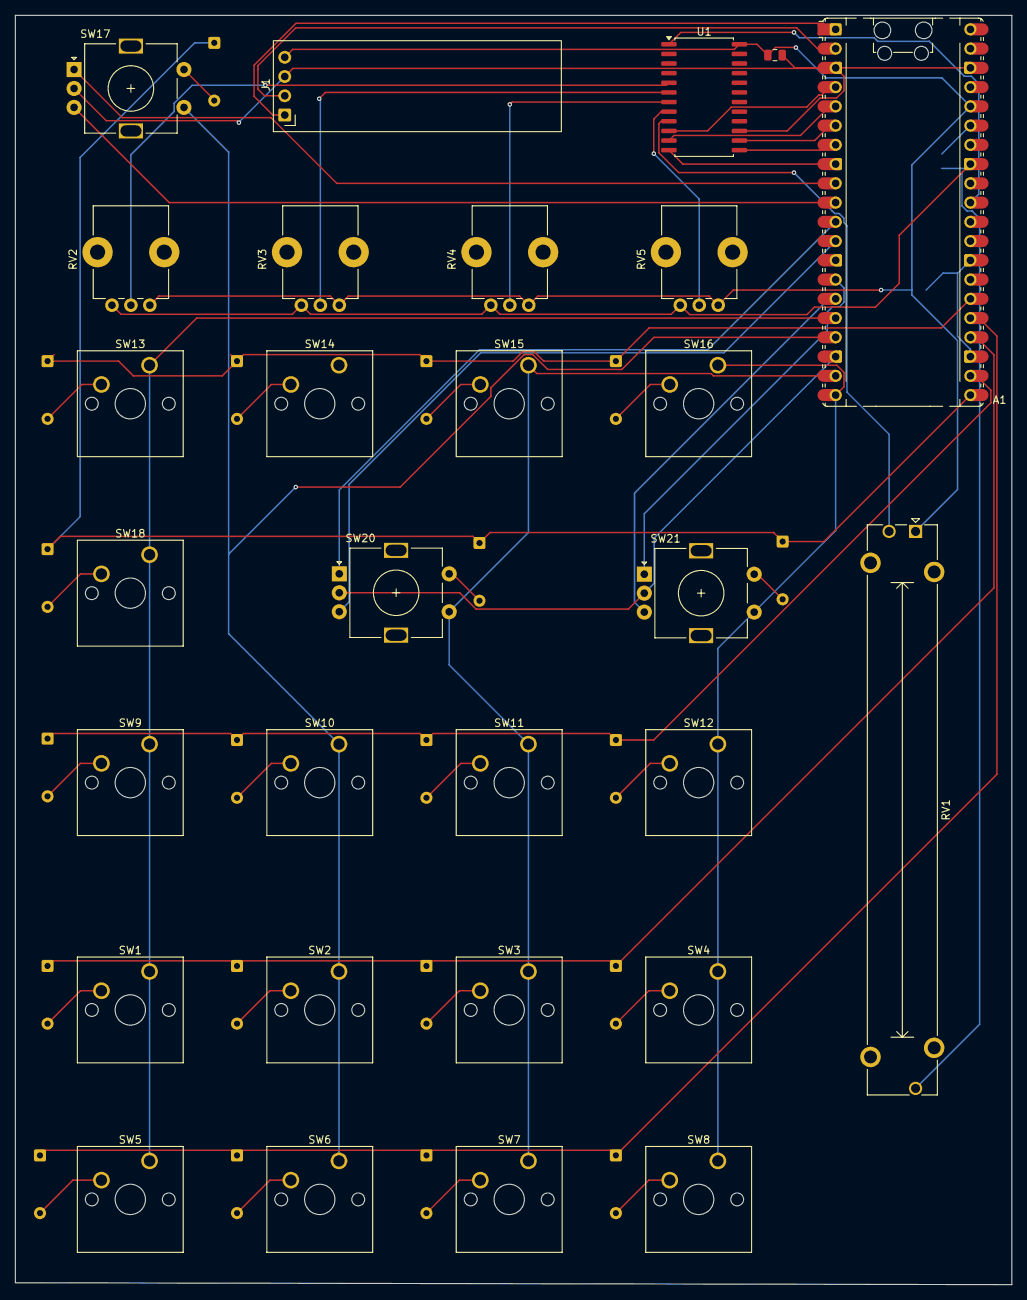
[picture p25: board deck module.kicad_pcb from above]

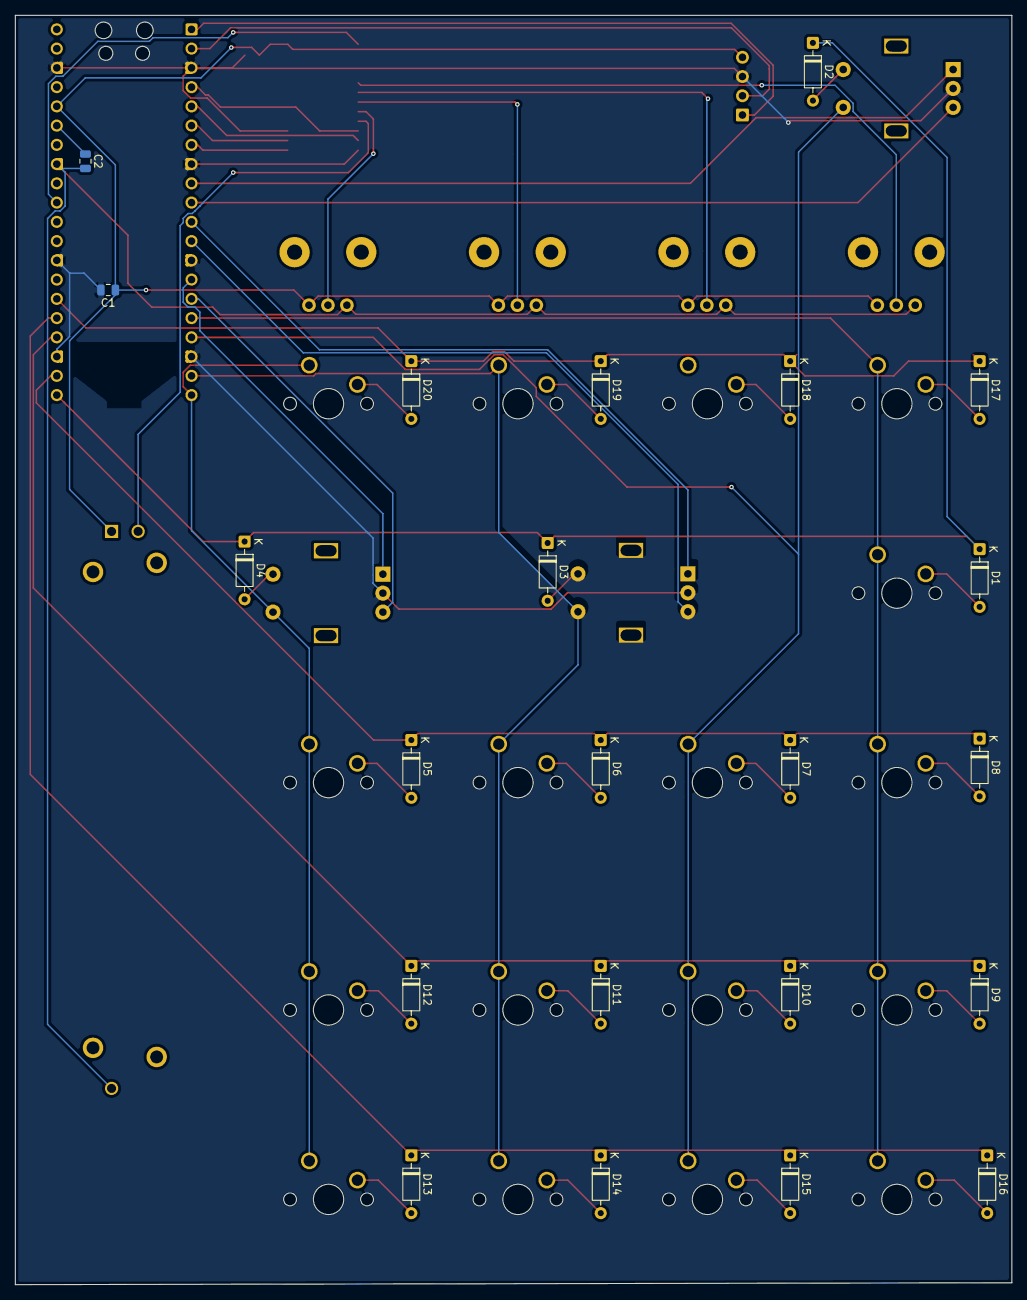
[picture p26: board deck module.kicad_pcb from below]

Board: 2 copper layers, 131.5 x 167.5 mm, 51 parts (22 on the bottom side), 51 nets.

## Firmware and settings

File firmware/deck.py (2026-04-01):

import board
import digitalio
import analogio
import rotaryio
import usb_midi
import adafruit_midi
from adafruit_midi.control_change import ControlChange
from adafruit_midi.note_on import NoteOn
from adafruit_midi.note_off import NoteOff
import adafruit_matrixkeypad

MIDI_CH = 1  # 2 for second deck
THRESHOLD = 2

midi = adafruit_midi.MIDI(midi_out=usb_midi.ports[1], out_channel=MIDI_CH - 1)

s_pins = [
    digitalio.DigitalInOut(p) for p in (board.GP2, board.GP3, board.GP4, board.GP5)
]
for p in s_pins:
    p.switch_to_output()
mux_adc = analogio.In(board.GP26)
last_analog = [0] * 5


def get_mux(ch):
    for i in range(4):
        s_pins[i].value = (ch >> i) & 1
    return mux_adc.value >> 9


rows = [
    digitalio.DigitalInOut(x)
    for x in (board.GP16, board.GP17, board.GP18, board.GP19, board.GP20)
]
cols = [
    digitalio.DigitalInOut(x) for x in (board.GP12, board.GP13, board.GP14, board.GP15)
]
keys = range(20)
keypad = adafruit_matrixkeypad.Matrix_Keypad(rows, cols, keys)
last_keys = set()

encs = [
    rotaryio.IncrementalEncoder(board.GP6, board.GP7),
    rotaryio.IncrementalEncoder(board.GP8, board.GP9),
    rotaryio.IncrementalEncoder(board.GP10, board.GP11),
]
last_enc_pos = [0, 0, 0]

while True:
    for i in range(5):
        val = get_mux(i)
        if abs(val - last_analog[i]) >= THRESHOLD:
            midi.send(ControlChange(20 + i, val))
            last_analog[i] = val

    cur_keys = set(keypad.pressed_keys)
    for k in cur_keys - last_keys:
        midi.send(NoteOn(30 + k, 127))
    for k in last_keys - cur_keys:
        midi.send(NoteOff(30 + k, 0))
    last_keys = cur_keys

    for i in range(3):
        pos = encs[i].position
        if pos != last_enc_pos[i]:
            msg = 127 if pos > last_enc_pos[i] else 1
            midi.send(ControlChange(40 + i, msg))
            last_enc_pos[i] = pos

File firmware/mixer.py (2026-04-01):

import board
import digitalio
import analogio
import usb_midi
import adafruit_midi
from adafruit_midi.control_change import ControlChange
from adafruit_midi.note_on import NoteOn
from adafruit_midi.note_off import NoteOff

MIDI_CH = 3
ANALOG_THRESHOLD = 2

midi = adafruit_midi.MIDI(midi_out=usb_midi.ports[1], out_channel=MIDI_CH - 1)

s_pins = [
    digitalio.DigitalInOut(p) for p in (board.GP2, board.GP3, board.GP4, board.GP5)
]
for p in s_pins:
    p.switch_to_output()

mux1_adc = analogio.AnalogIn(board.GP26)
mux2_adc = analogio.AnalogIn(board.GP27)

last_mux1 = [0] * 16
last_mux2 = [0] * 9

cue_pins = (board.GP14, board.GP15, board.GP16, board.GP17)
cue_buttons = []
for p in cue_pins:
    btn = digitalio.DigitalInOut(p)
    btn.direction = digitalio.Direction.INPUT
    btn.pull = digitalio.Pull.UP
    cue_buttons.append(btn)
last_cue_state = [True] * 4

while True:
    for i in range(16):
        for bit in range(4):
            s_pins[bit].value = (i >> bit) & 1

        m1_val = mux1_adc.value >> 9
        if abs(m1_val - last_mux1[i]) >= ANALOG_THRESHOLD:
            midi.send(ControlChange(50 + i, m1_val))
            last_mux1[i] = m1_val
        if i < 9:
            m2_val = mux2_adc.value >> 9
            if abs(m2_val - last_mux2[i]) >= ANALOG_THRESHOLD:
                midi.send(ControlChange(70 + i, m2_val))
                last_mux2[i] = m2_val

    for i in range(4):
        cur_state = cue_buttons[i].value
        if cur_state != last_cue_state[i]:
            if not cur_state:
                midi.send(NoteOn(10 + i, 127))
            else:
                midi.send(NoteOff(10 + i, 0))
            last_cue_state[i] = cur_state

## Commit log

2026-04-01 init commit
    [deck module-B_Cu.gbr, deck module-B_Mask.gbr, deck module-B_Paste.gbr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]
2026-04-25 add cad
    [deck assembled.step, deck bottom.step, deck module.dxf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]
